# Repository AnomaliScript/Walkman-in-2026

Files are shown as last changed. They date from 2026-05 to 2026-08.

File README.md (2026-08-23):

# Walkman-in-2026
As a part of Hack Club's "Fallout" challenge, I attempt to build a replica of Makoto's walkman (from Persona 3) using KiCad, Onshape, and hopes and dreams.

This Walkman composes of many capacitors, resistors, an Audio Jack, a microSD card socket, LCD display, four buttons, an on/off switch, and most importantly, a XIAO-ESP3-S3 to make it all work!
Most, if not all of these components are THT, or "through-hole technology", meaning that the components have pins that go through holes in the PCB, making them easier to soldier, and that's why I chose THT components (with the exceptino of the microSD card reader), because I'm not a soldering expert (yet).

## V0.1
I made my own custom "standoffs" which are supports that support the LCD display, because it needs extra vertical room in order for its pins to be connected to the PCB.  I 3D printed both a "screw" and a "non-screw" version of the standoffs, to test which one would work best (standoffs are small, and the smaller a print is, the worse small details, like screw patterns, will be).



The screw standoff's didn't work, becasue my 3D printer can't print with that amount of sub-millimeter precision, so I'll just have to use the "non-screw" version of the standoffs.

## V0.2
The biggest change from V0.1 was the addition of an Amazon-purchased breakout board that covered both the AudioJack (3.5mm diameter) and PCM5102A stereo.  After all, the PCM5102A is indeed a really tiny chip, and with the soldering iron that I was getting, it wasn't likely that I could've soldered the chip using SMD (surface mount) on my own.  Consequently, I had to rewire the whole PCB (this will happen many times...) to compensate for this change.
What I specifically did was delete the AudioJack and PCM components from the PCB, and put a 16-pin connetor row in its place to set it up for wires to connect to the breakout module (a decision I would later go back on).
I also cleaned up the BOM a little bit, but it still was missing a lot of components compared to the final one (which I will link in the bottom of this README).



I was planning to get many of my components from my school's makerspace, however since Georgia school years end in mid-May, I lost access to those spaces, and therefore couldn't access those resources: this meant that I had to go shop online (i.e. Amazon and Digikey).
V0.2 was also when I finally started to consider how to power this whole contraption, and the conclusion I came up with was simply to add some punches holes (called  "Jumper" in the KiCad schematic) to have the battery wires solder through.





## V0.3
The buttons on the Walkman PCB looks a bit off; maybe it's because they're not tilted 90 degrees!  While implementing right-angle switches, I learned about the different types of drill holes that KiCad offers (I had the wrong type of hole for the switches' footprints which was giving me DRC errors).



This was also when I became very insecure about my power management system, so this was when I learned that the XIAO-ESP3-S3 in fact has a built-in nattery management system that rules out the need for Buck converters and other auxillary power managemtn components, which was a huge relief after having done power research for a couple of days straight.  The only problem was how to get the power tracks/wires to connect to the bottom of the XIAO, becasue that's where the XIAO's battery pads (BATT) are.  Seeing as to how laying the XIAO against teh PCB would make it impossible for a wire to reach under the XIAO, I decided to elevate it using connectors (not shown in the KiCad 3D Viewer below).



## V0.4
I went back on my decision to physically elevate my XIAO from the PCB.
After a family vacation, my refreshed mind preferred to create pads on the XIAO footprint itself.  By adding the BATT pads onto the footprint itself, the XIAO, when it comes in contact with the PCB direcly, would have its BATT pads touch the PCB's corresponding pads, requiring no extraneous equiment to connect the two.
This customization of the orignal XIAO-ESP32-S3 footprint required me to refer to Seeed Studio's offical KiCad files in order to determine the dimensions and position of the BATT pads, becasue the XIAOs that I ordered were still in transit at the time, so I had no other reference.



The XIAO BATT pads and its PCB footprint counterpart, in theory, seemed to perfectly align with each other.



I also learned that I had ordered the wrong type of switch for the power, as I ordered a SW_SPST (a button) instead of a SW_DPST (an actual power switch that toggles), so I had to order SW_DPST switches.
The LCD that I got was also an unexpected (but plesant) surprise: it came with the PCF8574 component (a component that allows for more GPIO pins) already soldered onto the LCD1602.  After realizing that this aligned with my PCB schematic, I gladly deleted the PCF8574 from my schematic and PCB Editor, and more configuration was done.



Due to the unique pin that the LCD came with, however, I had to redo the footprint for the LCD as well.





## V0.5
Reviewing my the PCB, I realized that the 5V pin on the LCD wasn't connected to anything, and thus began the **third** reexamination of my PCB's power management.  After scrutiny, I fixed the 5V pin on the LCD fairly quickly (connect the 5V on the LCD to the VBUS pin on the XIAO), but there was another issue that I found, and it had to do with the BSS138 components.  BSS138s are what are called "bidirectional I2C level shifters", which means they mediate the translation between a higher voltage (e.g. 5V) and a lower voltage (3V).  Cleaning up my schematic to mitigate risks of making errors due to confusion, I then revised the BSS connections.



Once again, I had to rewire everything (BSS138 is a surface-mount/SMD component, which made rerouting a little harder).



I also noticed that I really needed a 3D model for the LCD component, becasue that was not only the biggest part, but it's also one of the most important parts when it came to me designing a housing/case for my PCB.  Surfing through the internet, I landed upon a sketchy-looking 3D model of the exact same component (I copied and pasted the Amazon name of the component into Google), and it was in some Autodesk-specific file format.  After registering for a free trial for Autodesk products (specifically Fusion 360), I converted into an .stl file and imported into OnShape to look at it further.  The model  wasn't that bad, and when I linked the 3D model to my LCD footprint on the PCB in KiCad, it fit right in!
One tiny change had to be made, and it was the deletion of the right-angle pins (I bent the pins on my LCD to make it straight to make it parallel to the PCB surface...I hope that doesn't mess up dimensioning...)

## V1.0
Remember the 16-pin connector that I mentioned?  Their job was to act as pins that wires from the AudioJack breakout module could connect to, but seeing as to how it adds unnecessary space to the Walkman, I designed the AudioJack component as a footprint in the PCB Editor to get rid of the 16-pin connector (this did in fact save a lot of space).  This required some dimensioning, which I did, and I made a rough OnShape model of it.  Exporting it onto the 3D Viewer in my PCB Editor on KiCad, I moved it up a bit (which will represent me using pinn connectors to elevate it) in order to give it some room so it doesn't collide with the right-angle switches.





I utilized my 3D printer to print simplified versions of my PCB to check the footprints and pin dimensions for the XIAO, LCD component, and AudioJack component (not pictured), but after verification I ordered the PCB from JLCPCB, and now I wait for it to come (as well as some other LCSC components).





# BOM (not including delivery fees + tariffs)
| Id | Name | Vendor  | Qty | Cost |
| --- | --- | --- | --- | --- |
| 1 | [microSD card slot](https://www.digikey.com/en/products/detail/molex/0472192001/3044807) | DigiKey | 10 | $14 |
| 2 | [BSS138](https://www.digikey.com/en/products/detail/onsemi/BSS138/244210)| DigiKey | 10 | $2 |
| 3 | [Power Switch (taken from my friend's recommendation)](https://www.lcsc.com/product-detail/Slide-Switches_C-K-OS102011MA1QN1_C226259.html) | LCSC | 10 | $5.25 |
| 4 | [XIAO ESP32S3](https://www.amazon.com/ESP32S3-2-4GHz-Dual-core-Supported-Efficiency-Interface/dp/B0DJ6NQFKX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) | Amazon | 3 | $27 |
| 5 | [1602 LCD + PCF 8524 module](https://www.amazon.com/Hosyond-Display-Module-Arduino-Raspberry/dp/B0BWTFN9WF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) | Amazon | 3 | $14 |
| 6 | [AudioJack + PCM 5102 module](https://www.amazon.com/PCM5102-PCM5102A-Digital-Converter-Raspberry/dp/B0DNW32Y46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) | Amazon | 2 | $9 |
| 7 | [1000mAh LiPo battery](https://www.amazon.com/1000mAh-battery-Rechargeable-Lithium-Connector/dp/B07BTWK13N) | Amazon | 1 | $9 |
| 8 | [Right-Angle Switches](https://www.lcsc.com/product-detail/C49101620.html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) | LCSC | 50 | $0.63 |
| X | X | X | X | ~$81 |

## Additional supplies

I started to get soldering supplies by asking my friend's dad for some, to which he responded with a simple roll of solder and an okay soldering iron.  This worked out fine for the simpler components, but when it came to more complex soldering assemblies such as SMD components, I needed help.
After some discussion with by more-experienced friend, he told me that I needed a pack of liquid/solid flux (just in case if the rosin-core solder didn't have enough), a heatbed for the SMD components, and some solder paste to complement the heatbed for easier soldering for SMD components.
| Id | Name | Vendor  | Qty | Cost |
| --- | --- | --- | --- | --- |
| 1 | [Heatbed](https://www.amazon.com/Soldering-Microcomputer-Technicians-Electronics-Enthusiasts/dp/B0G443BG4X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) | Amazon | 1 | $27 |
| 2 | [Flux](https://www.amazon.com/SRA-Soldering-Electronics-Lead-Free-Electrical/dp/B008ZIV85A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) | Amazon | 1 | $9 |
| 3 | [Solder Paste](https://www.amazon.com/Particle-Melting-Electronics-Welding-100G/dp/B0FYH9HS2W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) | Amazon | 1 | $22 |

After getting these components, I set up shop in my garage, and I opened the garage door so that the yummy lead fumes could escape.  However, I got moved to my back patio after my dad complained after a bunch of bugs came it in from the open garage door.

Finally, after having done most of the soldering to enable theoretical functionality for my Walkman, I tried hooking it up to my computer using a Logi USB-C cable, and after some vibecoding with Claude Opus, I got the Walkman to work...partially.  The display was a little off, and no matter how many times I unplugged and replugged my earbuds, I still couldn't hear anything from the Walkman.  Thankfully, the microSD card reader was working, as well as the LCD after some adjustment, because I saw it displaying the text of the songs that I had loaded onto the microSD card.

Switching out my earbuds for headphones that I usually use, I was finally able to hear the music that was playing!



However, the battery still needed to be implemented into the Walkman PCB, and I soon realized that the V1.0 Walkman PCB wouldn't be able to distribute the LiPo battery's power to all the peripherals on the PCB.  This was because I wired the AudioJack, LCD display, and all the other peripherals other than the microSD card to all use VBUS (5V) power instead of 3.3V power.  The problem lied in how the 3.3V pin, not the VBUS pin, was the only power distributor when the Walkman is disconnected from the XIAO's USB-C's power source.

## V2.0 
With the LiPo power distribution not working and the LCD screen not being entirely accurate to Makoto's Walkman in Persona 3, I returned to the drawing board that is KiCad.  By working with Claude, I found another [LCD screen](https://newhavendisplay.com/2x20-character-lcd-stn-gray-display-with-side-white-backlight-and-pin-header-3v/) online that looked more similar to Makoto's Walkman screen.  Looking at its datasheet, I tried adding it into my Walkman PCB schematic.

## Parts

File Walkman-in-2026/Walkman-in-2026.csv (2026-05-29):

Id | Designator | Footprint | Quantity | Designation | Supplier and ref
1 | C1, C2 | C_Disc_D3.0mm_W1.6mm_P2.50mm | 2 | 2.2
2 | C3, C5 | C_Radial_D5.0mm_H5.0mm_P2.00mm | 2 | 2.2
3 | C6, C7, C8 | C_Disc_D3.0mm_W1.6mm_P2.50mm | 3 | 0.1
4 | C9 | C_Radial_D5.0mm_H5.0mm_P2.00mm | 1 | 0.1
5 | C10 | C_Radial_D5.0mm_H5.0mm_P2.00mm | 1 | 10
6 | J1 | Jack_3.5mm_CUI_SJ1-3513N_Horizontal | 1 | AudioJack3
7 | J2 | microSD_HC_Molex_47219-2001 | 1 | Micro_SD_Card
8 | J3 | Molex_KK-254_AE-6410-02A_1x02_P2.54mm_Vertical | 1 | Conn_01x02_Socket
9 | Q1, Q2 | SOT-23 | 2 | BSS138
10 | R1 | R_Axial_DIN0207_L6.3mm_D2.5mm_P7.62mm_Horizontal | 1 | 33
11 | R2, R3, R4, R5, R6 | R_Axial_DIN0207_L6.3mm_D2.5mm_P7.62mm_Horizontal | 5 | 1k
12 | R7, R8, R9, R10, R11 | R_Axial_DIN0207_L6.3mm_D2.5mm_P7.62mm_Horizontal | 5 | 10k
13 | R12, R13 | R_Axial_DIN0207_L6.3mm_D2.5mm_P7.62mm_Horizontal | 2 | 470
14 | SW1, SW2, SW3, SW5, SW6 | SW_PUSH_6mm | 5 | SW_Push
15 | SW4 | SW_SPST_Omron_B3F-315x_Angled | 1 | SW_SPST
16 | U1 | XIAO-ESP32-S3-DIP | 1 | XIAO-ESP32-S3-DIP
17 | U2 | LCD1602 | 1 | HS1602A-B
18 | U3 | TSSOP-20_4.4x6.5mm_P0.65mm | 1 | PCM5102
19 | U4 | DIP-16_W7.62mm | 1 | PCF8574P

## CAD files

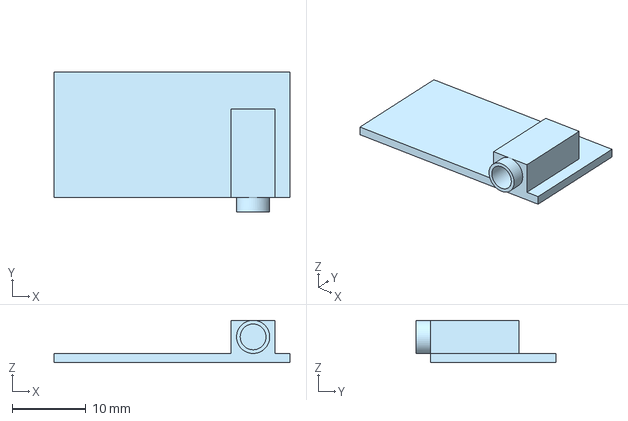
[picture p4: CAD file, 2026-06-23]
Walkman-in-2026/3d models/PCM + AudioJack.step
32.0 x 19.0 x 5.75 mm

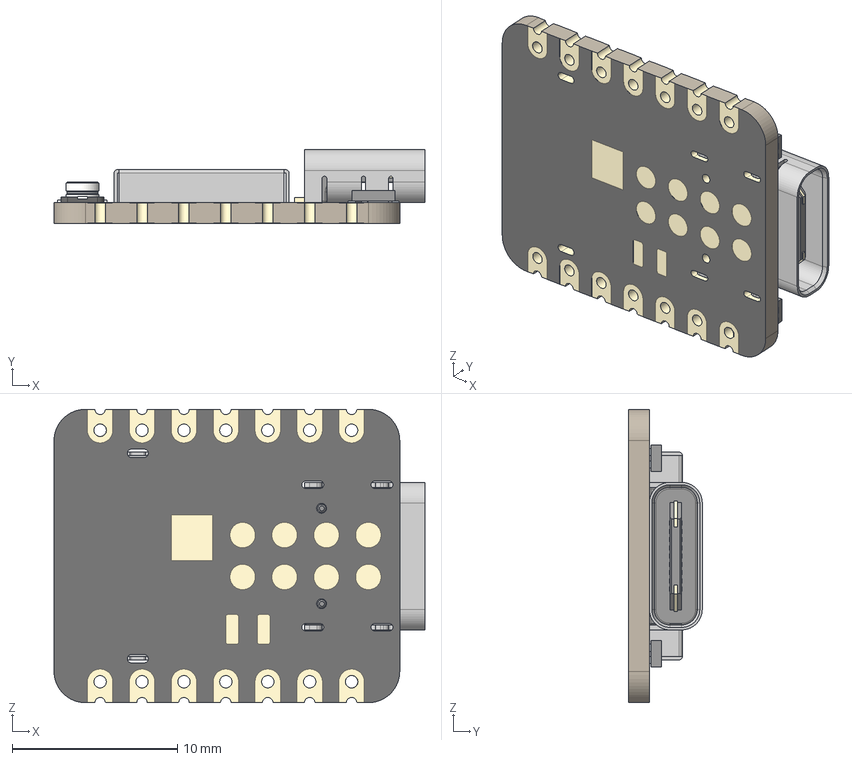
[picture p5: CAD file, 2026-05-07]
Walkman-in-2026/3d models/seeed-studio-xiao-esp32s3-3d_model/XIAO-ESP32S3 v2.step
22.5 x 4.46 x 17.8 mm
BOSS-EXTRUDE14_8_
BOSS-EXTRUDE7_4_
BOSS-EXTRUDE7_3_
BOSS-EXTRUDE14_4_
BOSS-EXTRUDE14_2_
BOSS-EXTRUDE14_11_
BOSS-EXTRUDE7_7_
BOSS-EXTRUDE14_9_
BOSS-EXTRUDE14_3_
BOSS-EXTRUDE14_7_
MIRROR2
BOSS-EXTRUDE14_5_
BOSS-EXTRUDE14_12_
BOSS-EXTRUDE7_8_
BOSS-EXTRUDE7_1_
BOSS-EXTRUDE14_10_
BOSS-EXTRUDE7_9_
BOSS-EXTRUDE14_6_
BOSS-EXTRUDE14_1_
BOSS-EXTRUDE7_6_
BOSS-EXTRUDE7_2_
CUT-EXTRUDE5
BOSS-EXTRUDE7_5_
Shield
Pins x 2
U.FL-R-SMT-1_10_ v1

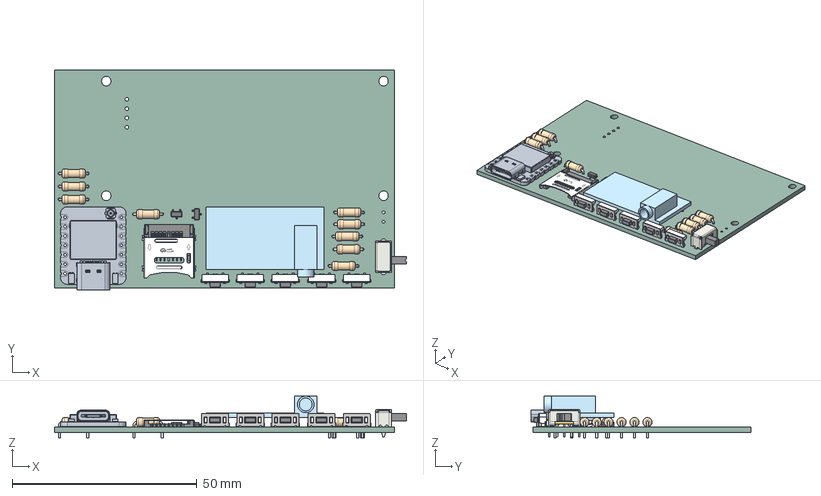
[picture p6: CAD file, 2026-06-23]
Walkman-in-2026/walkman v1.4.step
95.2 x 59.5 x 11.3 mm
XIAO-ESP32S3 v2
SW-SMD_TC-S3601-3.5-260G-F0.6 x 5
PCM + AudioJack
R_Axial_DIN0207_L6.3mm_D2.5mm_P7.62mm_Horizontal x 9
TF-SMD_472192001
SW_Slide_SPDT_Angled_CK_OS102011MA1Q
Surface 2
Surface 66
Surface 50
Surface 34
Surface 18
Surface 98
Surface 82
Surface 64
Surface 48
Surface 32
Surface 16
Surface 96
Surface 80
Surface 62
Surface 46
Surface 30
Surface 14
Surface 94
Surface 78
Surface 20
Surface 27
Surface 4
Surface 11
Surface 84
Surface 91
Surface 68
Surface 75
Surface 52
Surface 59
Surface 36
Surface 43
Surface 25
Surface 9
Surface 100
Surface 89
Surface 73
Surface 57
Surface 41
Surface 23
Surface 7
Surface 87
Surface 71
Surface 55
Surface 39
Surface 3
Surface 67
Surface 51
Surface 35
Surface 19
Surface 1
Surface 99
Surface 83
Surface 65
Surface 49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

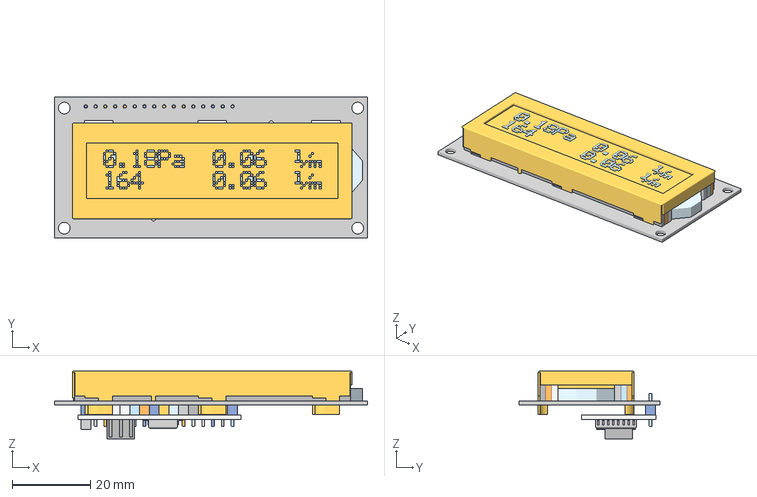
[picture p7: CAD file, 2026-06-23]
Walkman-in-2026/3d models/LCD 1602 I2C (pin removed).step
80.0 x 36.0 x 17.3 mm

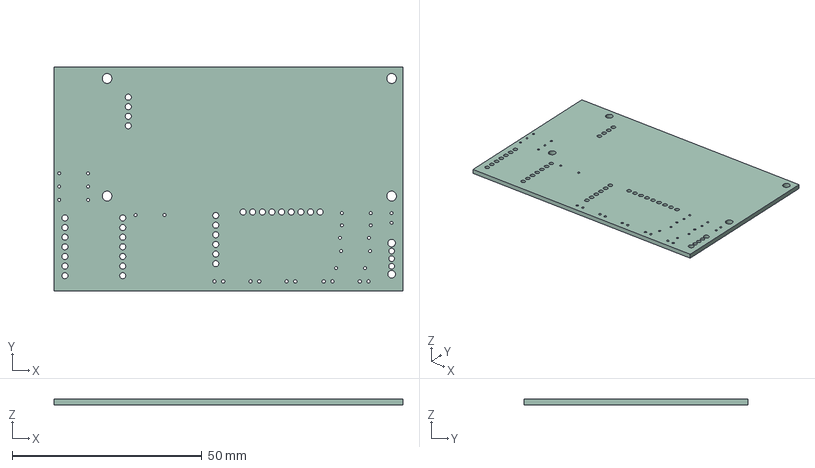
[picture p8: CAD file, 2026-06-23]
Walkman-in-2026/walkman v1.4 board.step
92.0 x 59.0 x 1.51 mm

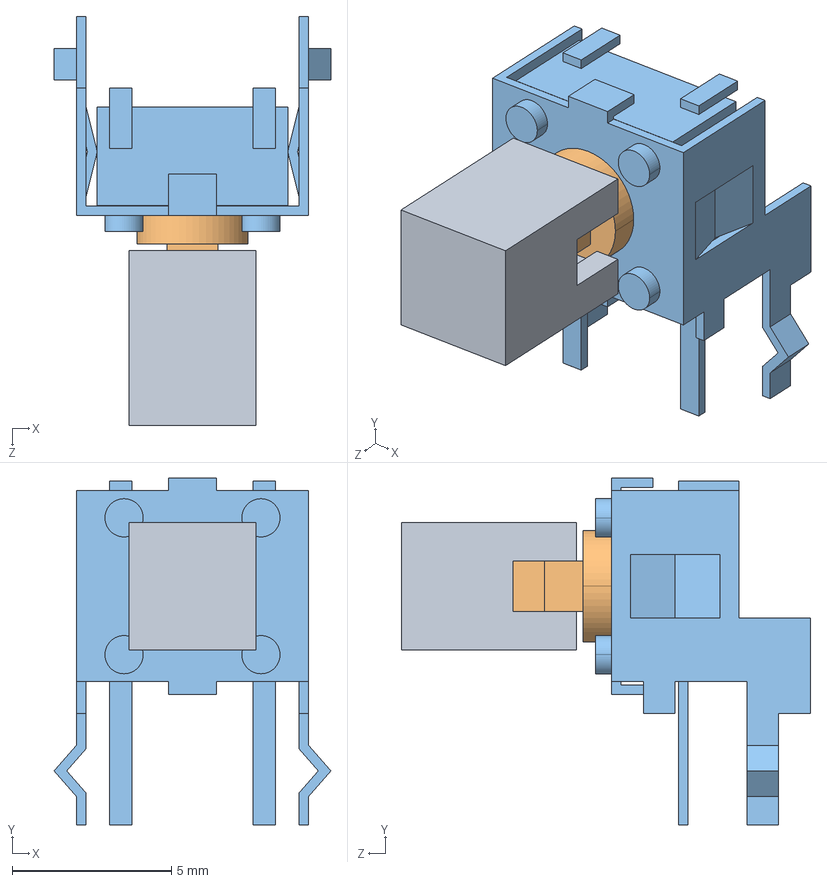
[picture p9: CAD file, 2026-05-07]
Walkman-in-2026/3d models/B3F_3150.step
8.70 x 10.9 x 12.9 mm
B32_1000
B3F_3150_BUTTON
B3F_3150_BASE

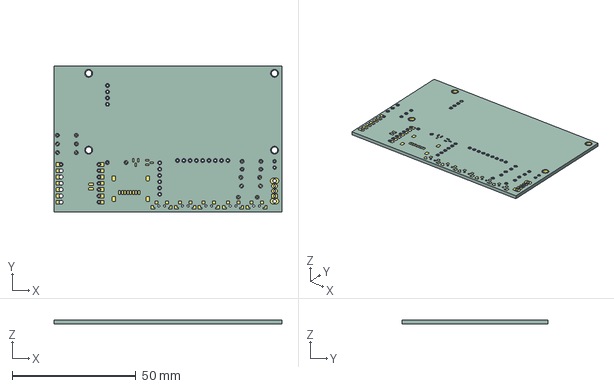
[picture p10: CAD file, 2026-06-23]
Walkman-in-2026/walkman v1.5 board (pads).step
92.0 x 59.0 x 1.59 mm
Walkman-in-2026_pad
Walkman-in-2026_PCB

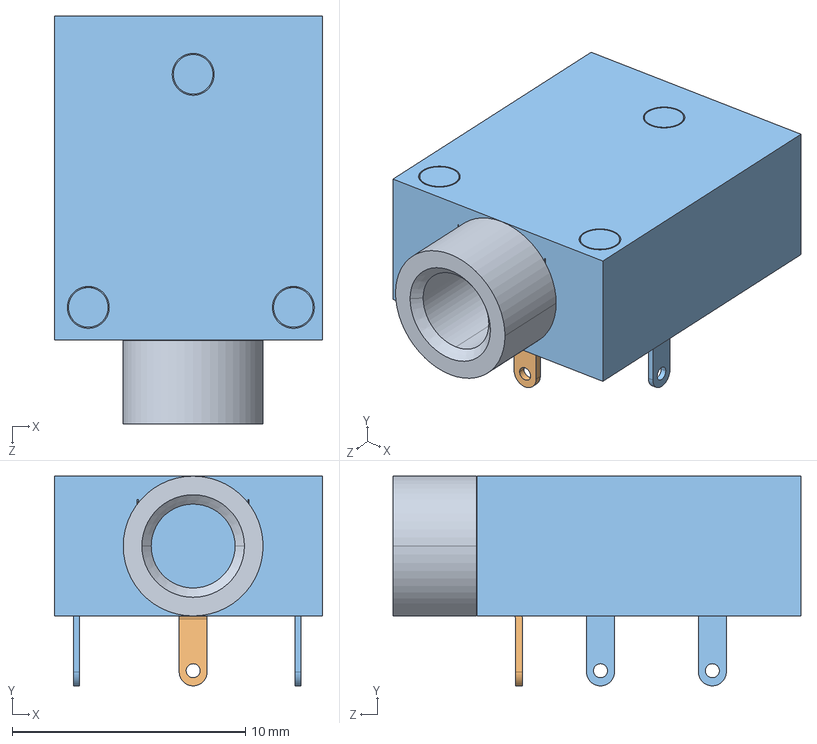
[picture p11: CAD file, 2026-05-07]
Walkman-in-2026/3d models/Same_Sky_SJ1-3513N.step
11.5 x 9.00 x 17.5 mm

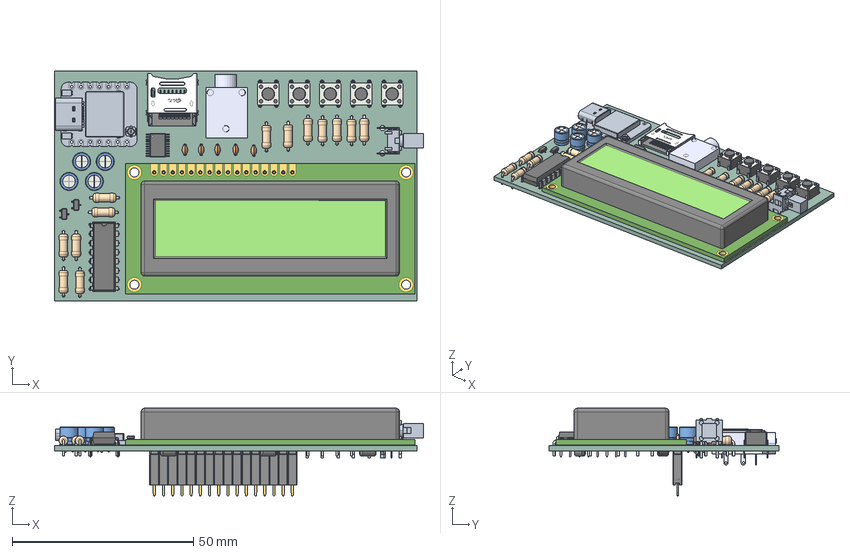
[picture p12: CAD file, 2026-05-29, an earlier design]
Walkman-in-2026/old_models/walkman v0.step
101.9 x 63.5 x 24.2 mm
C_Radial_D5.0mm_H5.0mm_P2.00mm x 4
C_Disc_D3.0mm_W1.6mm_P2.50mm x 5
XIAO-ESP32S3 v2
SW_PUSH_6mm x 5
R_Axial_DIN0207_L6.3mm_D2.5mm_P7.62mm_Horizontal x 13
TF-SMD_472192001
B32_1000
B3F_3150_BUTTON
B3F_3150_BASE
LCD1602̜ͥ
HDR-M-2.54_1x16-Áã¼þ
HDR-F-2.54_1x16-Áã¼þ
SOT-23 x 2
TSSOP-20_4.4x6.5mm_P0.65mm
DIP-16_W7.62mm
Same_Sky_SJ1-3513N
Walkman-in-2026_PCB

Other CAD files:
Walkman-in-2026/walkman v1.5 board.stl
Walkman-in-2026/walkman v1.5 board (pads).stl

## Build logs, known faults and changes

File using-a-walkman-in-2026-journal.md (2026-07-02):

# Using a Walkman in 2026 — Journal Export

- Exported at: 2026-07-02T14:07:46Z
- Project ID: 2332
- Entries: 37

## Entry 1
- ID: 3008
- Author: Brandon
- Created At: 2026-04-20T03:36:53Z

### Content

Today, I started my KiCad journey into making my Walkman actually happen, where I read up on the tutorial for KiCad, and did some research: it turns out the preferred MCU for my Walkman would be the **XIAO-ESP32-S3** (according to Gemini) because of its Bluetooth capability, because I would like the option to switch to my AirPods if wired earbuds got too annoying.

I looked further into the differences between the C6 and the S3 variants.




WHAT? You're telling me there's more than one type of ESP23-S3?!


I later learned that these differences are based on how the components will be attached to the solder board, and used this YouTube video to educate myself on how each type of manufacturing style works: https://youtu.be/UwTBCpqqacU?si=3JkgFAU-7ZSq832C (huh, this video also has Chinese captions)
I ended up choosing the SMD_PAD manufactured one, as it will allow me to hand-solder the part onto the PCB.

After this, I pursued to find a display for my Walkman replica: one that was thin and slim, but not too slim.  I finally found one on LCDC: https://www.lcsc.com/product-detail/C18198249.html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
Importing it into KiCad (specifically the Schematic) eas a nightmare.  Even through there was a gudie that helped me what to do, it still took me an hour and then some to get just the display of it on there: from using Gemini to watching Indian YouTube tutorials, I did it all, and found the schematic with two things: the ESP32 and the OLED Display screen.

### Recording Links

- https://lookout.hackclub.com/api/media/1aadc8eb-a1a8-465c-8510-a7b3c4f2bbd3/video.mp4

## Entry 2
- ID: 3151
- Author: Brandon
- Created At: 2026-04-21T03:36:40Z

### Content

Today was a full-on research day, where I learned about DACs (Digital Analog Connectors iirc?) and how they are important to translate audio data into a form where I can listen to music through a head phone jack (J1).
And because this is a music-playing device, I had to have a storage of some kind...hm....a microSD card!
Unfortunately, the poor XIAO didn't have enough room/pins to handle both the LCD display and the pins required for the MicroSD card (I also learned about MISO and MOSI pins for storage components like microSD cards).  Thus, I had to use a thingy called I2C (Inter-Integrated Circuit, I think), which is a technology that connects components together, especially peripherals.  This also meant: MORE PINS! YAY!

Unfortunately, it's bedtime, so I'll work on using Claude to help me know where each pins go.  I also looked up some of my first datasheets today: I'm starting to feel like a electrical engineer now!
(This is the datasheet for the pcm5102, which I'm pretty sure is a DAC that does the analog audio data translating for my headphone jack).
Screenshot 2026-04-20 232044.png

### Recording Links

- https://lookout.hackclub.com/api/media/c7bf1d50-8d7d-4dc5-8d09-0e8311dab583/video.mp4

## Entry 3
- ID: 3813
- Author: Brandon
- Created At: 2026-04-25T03:59:19Z

### Content

I am so close to breaking my streak it's 11:51PM rn T-T
Today was a wild PCB designing day for me...let be begin by talking about my trying to free up a pin for my Resistor Ladder on the XIAO ESP32 S3.  Basically it needed an analog pin (ADC) but all the rest of the pins on the MCU were taken by the LCD display pins, so I had to import and look for a I2C backpack (PCF8574P) to implement in my PCB.  After spending a while adding the PCF8574P to my schematic, I connected the display pins to the PCF8574P, and rerouted the Resistor Ladder with all my switches (buttons) go to the XIAO's now-free A0 pin.  Yippee!

After, I worked on the 3.3V (XIAO and PCF8574P) and 5V (LCD) difference, because wiring those together would "wear out" the PCB, so I've heard, so I chose to add a MOSFET (BSS138) to the PCB to manage that.

There's a lot more I can talk about, but I need to turn in my journal in now, I'll talk about it more in my next entry, bye for now!
Screenshot 2026-04-24 234217.png

### Recording Links

- https://lookout.hackclub.com/api/media/1ea78349-316f-401f-9d6a-252b5c26c8a0/video.mp4

## Entry 4
- ID: 3963
- Author: Brandon
- Created At: 2026-04-26T00:39:55Z

### Content

Review of what I did in the last journal entry, since couldn't complete the full entry due to me having to submit it before midnight (I submitted it at 11:59PM!)

_I learned all about the different pins that the Micro SD Card had, and how their pins relate to the MOSI and MISO pins in the XIAO ESP23-S3.  The data goes into the MOSI from the card, and the MISO sends out data to the card...I think.  Anyways, I used Claude to help me summarize a datasheet for the stereo ADC that I had to use to bridge between the AudioJack and the XIAO ESP23, and it turns out that TI (Texas Instruments), really wants me to put a whole slew of caps (capacitors) onto their PCM5102 to ensure "safety" or something...not quite sure of the exact reason yet...and after getting the news that I had to place a bajillion caps on there, I signed off for the night.  

And that is where we continue my Walkman journey today..._

Continuing where I left off yesterday night, I had a hard time connecting the rest of the pins and learning about the audio stereo ADC component that I was working with (specifically, the PCM5102).  **This was because I had to work on my PCB with my battery-deficient laptop, where it almost constantly had to be connected to a power outlet, and I even forgot to bring my mouse!**


What will I do without my precious right-click and scroll-wheel? T-T  (For context about why I didn't have access to my desktop is because I was volunteering at a jazz music festival all-day today)

Thus, I accomplished less than what I hoped for.
During this session, I also learned about "bypass capacitors", which are mechanisms where a capacitor is placed between a GND (ground) point and intersection where power is flowing to the pin (in this case, the CPVDD, DVDD, and AVDD pins ) in order to manage power "spikes" that would happen that result from turning switches on and off.


Luckily, I finally ended up with my first version of the (what is think is the) entirety of the schematic, now I just have to check it!  (Ugh, checking...)

### Recording Links

- https://lookout.hackclub.com/api/media/7c59ccf2-c480-4df7-b77c-4ef2a79f002e/video.mp4

## Entry 5
- ID: 3987
- Author: Brandon
- Created At: 2026-04-26T03:27:34Z

### Content

This time, I was pressed for time and I only could ask Claude for the BOM about what specific materials and component models I should get for the resistors, AudioJack, capacitors, etc for all the stuff that I was going to need to solder onto the board.

Claude gave me the difference between THT and SMD socket components, which led me to make some decisions (as I had some experience with soldering before through my robotics club, I thought that I would be able to hit them up for some soldering help for SMD soldering to help preserve space on my PCB).
Screenshot 2026-04-25 224140.png

### Recording Links

- https://lookout.hackclub.com/api/media/c29a6eed-b1fe-4980-970e-7d8049d6ec55/video.mp4

## Entry 6
- ID: 3991
- Author: Brandon
- Created At: 2026-04-26T03:46:02Z

### Content

This session was really short, because I was doing this between chores (my parents are inviting friends over all of a sudden T-T)
Anyways, I continued my research into seeing if the Molex version of the aforementioned microSD Card reader is the same as the microSD Card reader that I chose in the KiCad footprint editor: I'll have to look at KiCad's rendition of the dimensions of the microSD Card Reader in my next session.
However, I did manage to get some dimensions of the microSD Cards that are available on LCSC, a sister company of JCLPCB that share many of the same supplies and components, so I hope there's a high chance of seeing the exact component that was listed in KiCad.



### Recording Links

- https://lookout.hackclub.com/api/media/58d2fc34-4e16-444e-9bb2-855d7b3ae880/video.mp4

## Entry 7
- ID: 4285
- Author: Brandon
- Created At: 2026-04-28T01:03:31Z

### Content

In this session, I went into the footprint editor for some of the components (in the following screenshot I inspect the microSD Card reader by molex), and sure enough, these dimensions match the ones listed in their datasheets!
Screenshot 2026-04-27 182044.png

After that, I went through all of these components and used the Internet and Claude to search for which components would be best for my project:
- Audio Jack
- Switches (Buttons)
- Switches (Single Pole Single Throw switches)
- Resistors
- Capacitors

For example, here is the list of all the buttons that I was considering:
Screenshot 2026-04-27 182501.png

During the process of looking for resistors, I got to refresh some of my Physics class learnings by using Ohm's law to try to calculate the required Power (in Watts) that a resistor had to have in order to be suitable for different parts of my PCB.  I learned the Power Law (i.e. P = I^2 * R) by doing this, and Claude helped me go through the formulas and calculations. (Of course, I could've gotten it to just tell me what products to get, but I like to know the "why" behind technical things like this!)

I also learned about the different kinds of resistors available to me (I chose the SW_PUSH_6.0mm one):
[](url)
Screenshot 2026-04-27 184148.png

As I finished the BOM, I realized that I may not need an audio jack, because **my wired earbuds that I have in fact use the Lightning cable**...so I'll have to fix that before I move onto the PCB editor.

### Recording Links

- https://lookout.hackclub.com/api/media/3459b02a-e108-41c2-8270-5c5de9bcffd9/video.mp4

## Entry 8
- ID: 4342
- Author: Brandon
- Created At: 2026-04-28T12:22:34Z

### Content

Today I cleaned up the PCM wiring, because I made the mistake of trusting Claude to do all the thinking of telling me where to wire things for me.  Even though I gave it the pdf of the PCM 510x datasheet, it still messed up some things for my schematic.  Some intersections between wires were missing, and the direction was off in all the wiring, although Claude had gotten all the resistances and powers right for the capacitors and resistors.
Here's the real configuration of the PCM according to Texas Instruments:


This was a headache figuring this out, as I had to move other components on the schematic to make room for rewiring the PCM.

After getting that sorted out, I was unpleasantly surprised to see that I was getting errors that KiCad couldn't find my MCU's footprint (i.e. XIAO_ESP32_S3) for the PCB Editor!  I had to scour through my /Documents, and sure enough, I forgot to include the .pretty folder that was supposed to contain the footprint for the MCU.  Going back to the page where I originally got the XIAO_ESP32_S3 for the schematic (https://wiki.seeedstudio.com/XIAO_ESP32C3_Getting_Started/#resources), I downloaded the zipped footprint file, and placed it inside the GitHub-tracked folder, so that I could continue working on it on other devices.


After doing so, I hoped that the footprint would appear when I went int the "Assign Footprints" page, and surely enough, it was there!  I pressed F8 triumphantly, and went on to bring the last, but certainly not least, component onto the PCB editor.
Screenshot 2026-04-27 230242.png

...
There's going to be a lot of work to do in the next few days.
Organizing this mess will take a while.

Before I signed off, however, I placed all the components into a box-like shape, where the enclosing perimeter barely was within regulation (100mm x 100mm).  I'll have to squeeze these things tighter if I want to make this project happen!
Screenshot 2026-04-27 230855.png

Also here's what the reference of the XIAO_ESP23_S3 looks like in the PCB Editor compared against the real footprint of the MCU.  Turns out they're not the same.  That's so tricky, how the refence of the MCU can appear even if the .pretty file for it wasn't imported yet!
Screenshot 2026-04-27 230333.png

### Recording Links

- https://lookout.hackclub.com/api/media/d9cb07e5-026a-4644-827f-7c0e6f55e56c/video.mp4

## Entry 9
- ID: 4717
- Author: Brandon
- Created At: 2026-05-01T04:41:58Z

### Content

Today was all about the PCB Editor.  I tried to move around some wiring stuff, but there's only so much I could do with only a front and back copper wiring, and I soon had thousands of vias all over the PCB, which at that point I decided to reset EVERYTHING using KiCad's "Global Deletions" tool, and selecting all the copper paths, wires, and vias.


It was sad having to restart after I tried to make some headway into my wiring for the past 45 minutes, but it had to be done, in order to prevent more "via hell".  After I restarted, I moved the resistors to be above (farther up than) the LCD display, which simplified some wiring things.  I have to sleep now, but hopefully I can finish this wiring tomorrow and ask for someone to review it.

### Recording Links

- https://lookout.hackclub.com/api/media/f4e20d62-6b0a-4424-9013-4a711fbb8479/video.mp4

## Entry 10
- ID: 5224
- Author: Brandon
- Created At: 2026-05-03T04:49:09Z

### Content

Today I had to deal with PCB designing on my crappy laptop again because I was busy with scouting matches at the FIRST Championship in Houston (I stopped by the Hack Club booth, it was cool!)
Between bus rides back and forth from the hotel, I attempted to continue wiring my PCB together in KiCad's PCB Editor.
Screenshot 2026-05-01 080658.png
After a bit, I was trying my best to minimize the vias and make the routes as short as I could, but at a certain point, I decided to reset all the tracks and wiring and start over...again.
When taking a break from scouting matches at the FRC Championship, I came up with the brilliant (but obvious) idea of using the schematic to determine which components should be closer to certain components.
For example, I placed the XIAO ESP23 to be in the corner of the PCB, where it's more accessible to the PCM and PCF so not as much wiring would be required.
Screenshot 2026-05-02 200527.png

### Recording Links

- https://lookout.hackclub.com/api/media/081d1a5d-8d79-4d58-8523-e08076eebd12/video.mp4
- https://lookout.hackclub.com/api/media/9c58167b-8520-4ebc-a850-b66e88b1f017/video.mp4

## Entry 11
- ID: 5372
- Author: Brandon
- Created At: 2026-05-04T03:03:11Z

### Content

Today, I kept working at the track hell that I had to do...this time, the focus of my sessions was in the PCM side of things.  The PCM connects to resistors, MIcro SD, the XIAO, Capacitors, literally everything so this made my head dizzy.  Not to mention, all the pins leave to space between them to let tracks go in between them, and **they are all front-copper (red) pins!**
This is a picture of me resorting to rotate the PCM in order to try to find a better way to organize it so that it results in fewer cross-overs and via craziness (i.e. the PCM pins are closer to their destinations to a greater extent).  What you see here is what the tracks were left behind when I dragged the PCM out of the frame of the PCB in order to rotate it separate from the whole PCB chaos.
Screenshot 2026-05-03 222950.png
Finally, after grueling work (not really, but it was tedious) I got a version of the PCM wiring (with less than 15 vias! yay...).
I never verified that having less vias is better for a PCB, but according to my common sense, less vias -> better
Screenshot 2026-05-03 225528.png

### Recording Links

- https://lookout.hackclub.com/api/media/d54699b7-06cb-4a69-8d3b-d5952ae25e61/video.mp4
- https://lookout.hackclub.com/api/media/aa61b15c-58b1-4517-ae1a-48ab2f16fae1/video.mp4

## Entry 12
- ID: 5540
- Author: Brandon
- Created At: 2026-05-05T03:11:13Z

### Content

Today, I finally attempted to close out the tracks in the PCB design, and since I did the hard stuff before (i.e. the PCM and micro SD card pins), it was relatively easy for me to do.

What wasn't as easy, however, was running the DRC and troubleshooting every error and warning.  One of the first errors that I fixed was the overlap of these pink outlines of the components: they're called courtyards.

In my case, the two BSS components that I had had overlapping courtyards, and here's the before and after the error:
Screenshot 2026-05-04 220401.png
Screenshot 2026-05-04 220605.png

Moving it was a bit annoying, as I had to rewire and track every one of the tracks that were connected to it.  I looked up a way to be about to move the component only in KiCad and have the tacks connected to it update themselves, but what KiCad offered, the "Drag" tool (activated by pressing "d") didn't work very well in my PCB because of the sheer amount of track and wire action going on.

After, I noticed that I kept getting an error about "malformed Edge.Cuts" shape, and I was initially confused, until I realized that I never defined a shape for the PCB, and only defined silkscreen shapes to outline the rough size restrictions for my PCB (100mm x 100mm).  Following this, I unfortunately discovered that the XIAO-ESP23-S3's footprint was barely outside the Edge.Cuts border.  To fix this, I had to move the XIAO back into the PCB.
Screenshot 2026-05-04 222547.png

I wanted to see the current version of the PCB in its 3D form: here it is as of right now!
Screenshot 2026-05-04 225843.png

### Recording Links

- https://lookout.hackclub.com/api/media/d5e59945-c8f8-4c8d-9821-e8e7d1448bd1/video.mp4

## Entry 13
- ID: 5680
- Author: Brandon
- Created At: 2026-05-06T03:59:44Z

### Content

Today is the day where I import my Gerber files (zipped) into JCLPCB and see how much it costs!
Of course, I chose the cheapest delivery price, and it was pretty cheap (of it may be because all of the deals I'm getting as a new JCLPCB member).
Here's me realizing that I need to get to reimport the Gerber files because I forgot to include some of the files.
Screenshot 2026-05-05 231304.png
Screenshot 2026-05-05 231408.png
This is me ordering my last PCB project because I didn't finish the process of buying it last time.
Screenshot 2026-05-05 232029.png
Screenshot 2026-05-05 232422.png
I also exported the 3D rendering of my Walkman rn!
Screenshot 2026-05-05 234517.png

### Recording Links

- https://lookout.hackclub.com/api/media/bdf27283-ae1d-45e6-8739-f536f6d2cbec/video.mp4

## Entry 14
- ID: 5831
- Author: Brandon
- Created At: 2026-05-07T02:45:31Z

### Content

After getting some rest last night (I got to sleep in because of AP exams), I found all the rest of my 3D models for my PCB in order to get an accurate visual representation of my PCB so that I could import it into OnShape so that I can start making a 3D printed case for it to protect it.
During my importing process, I had to go file hunting in my Walkman/ and Program Files/KiCad/ folders, because when I use easyeda2kicad, it outputs the .step 3dmodel files for the components into the Program Files/KiCad/ and I placed them into my Walkman/ folder (that is being tracked using GitHub Desktop).  I did this to maintain continuity, dunno if this is bad file management as an electrical engineer.  (Guess I'll find out the hard way later)
Screenshot 2026-05-06 212219.png
Screenshot 2026-05-06 213040.png
Screenshot 2026-05-06 213817.png
Screenshot 2026-05-06 215306.png
For the SPST switch, KiCad didn't have the 3D model in its Program Files for some dumb reason, so I had to create an account for Omron [https://components.omron.com/us-en/](url) and downloaded the SPST switch 3D model directly from there (specifically, it was from the B3F series).
Screenshot 2026-05-06 221542.png
Here's what my PCB 3D rendering looks like now!  (Also sorry for the short journal entry yesterday: it was because I was writing up my entry at 11:58PM .-.)
Screenshot 2026-05-06 221612.png

### Recording Links

- https://lookout.hackclub.com/api/media/abaec749-8537-4eda-8e71-62728c9de4de/video.mp4

## Entry 15
- ID: 6201
- Author: Brandon
- Created At: 2026-05-09T03:59:42Z

### Content

So sorry but I have to use next journal entry to document my progress, the deadline (midnight) is coming up fast


### Recording Links

- https://lookout.hackclub.com/api/media/9289bfb3-3035-4c9d-a1b8-d4c7699f0ab0/video.mp4

## Entry 16
- ID: 6204
- Author: Brandon
- Created At: 2026-05-09T04:28:51Z

### Content

[This entry is for the last journal entry due to midnight closing in fast and I wanted to maintain my streak, thus the dummy Lookout Timelapse]
Diving deeper into 3D rendering inspection, I noticed that the pins on the LCD and the Audio Jack looked especially odd, and after fixing the Z axis of the Audio Jack in the 3D rendering, I went and asked Gemini what was going on with the LCD Display screen.
Screenshot 2026-05-08 213641.png
This wasn't my first time seeing the LCD's unique "blocky" pins compared to the other components, but I just never asked or questioned it up until this point.  Seeing that the pins just protrude through the PCB, I decided to finally find out what is actually supposed to happen with that LCD display.  Turns out, after research and looking at this [video](https://www.youtube.com/watch?v=qkb5_Wu0lgk), I couldn't believe that this LCD is supposed to be "dangling", only supported by the blocky pins that it has--well that's the way it is, I guess.
Screenshot 2026-05-08 214419.png
So after this discomforting discovery, like a good STEM student, I was concerned about the LCD display's support and the possibility of it breaking off or bending the pins (even though I going to build a case for it anyways).  This led me to the discovery of "standoffs", which are supports built for the corner holes in the LCD display.
Screenshot 2026-05-08 233544.png

Screenshot 2026-05-08 233922.png
After doing some more digging, I conveniently found a file for 3D printing these "standoffs", and given that I have a 3D printer, this worked out for me!  (I found the 3D prints [here](https://www.thingiverse.com/thing:4963899))
Screenshot 2026-05-08 234053.png

### Recording Links

- https://lookout.hackclub.com/api/media/e649ba19-e280-4b08-a3d2-dc83b9d8bf2d/video.mp4

## Entry 17
- ID: 6374
- Author: Brandon
- Created At: 2026-05-10T03:48:45Z

### Content

I made my own custom "standoffs" which are supports that support the LCD display, because it needs extra vertical room in order for its pins to be connected to the PCB. I 3D printed both a "screw" and a "non-screw" version of the standoffs, to test which one would work best (standoffs are small, and the smaller a print is, the worse small details, like screw patterns, will be).
Screenshot 2026-05-09 231951.png
Screenshot 2026-05-09 233715.png
I sliced my custom 3D prints using OrcaSlicer (despite not having my PCB and components on hand yet because I was waiting on another PCB to be shipped first), and decided that I needed to thicken some of my standoff and nut dimensions, because the slicer gave me a reality check about how small these things actually were.
Also, I made sure to send the sliced 3D prints to my 3D printer by running to my printer and turning it on, and then running back to my computer to send the files via OrcaSlicer (and no, I did not start printing during when the Lookout was recording my session)
Screenshot 2026-05-09 232901.png
So smol they only need one popcorn 🥹

### Recording Links

- https://lookout.hackclub.com/api/media/1fb45dbc-32ee-447d-84f2-66c8de7aed37/video.mp4

## Entry 18
- ID: 6872
- Author: Brandon
- Created At: 2026-05-13T03:56:45Z

### Content

I had to review the datasheet and information about the XIAO-ESP32-S3 again with [this link](https://wiki.openelab.io/seeed-studio/xiao-esp32s3).
This session challenged me a lot, and by "challenge" I mean it reminded me that PCBs need batteries in order to run portably.  (Well duh...)
Ok, in my defense, I assumed that the XIAO having battery power management to be able to take in power without needing a middleman meant that it could store power independent of other sources, but no, I was wronggggg.
Before that, though, I did some researching about the volumes that I could play my "jukebox" at, and I found a cool table that broke down what configurations would give me different sounds (I chose 12dB gain, I want my music to be heard!):
Screenshot 2026-05-11 211124.png
I was also given a pinout diagram, which was a cool find (and useful, these things are just copy-paste :D)
Screenshot 2026-05-11 212826.png
Back to the main topic: I FORGOT ABOUT THE BATTERIES (for BOTH the Walkman project and the Jukebox project, for the latter of which it wasn't such a big deal).  
For the Walkman project:
After scrambling to find some way to get a wire from my battery connected back to the PCB, which has to be externally connected (from the back of the PCB) due to space constraints and aura loss (I mean, who wants to have a big brick hanging on their lanyard like that?  Remember, I want the Walkman to be as similar to Makoto's thingy as possible).  Anyhow, I tried using a Screw Terminal to connect the battery pack (LiPo) to the GND
Screenshot 2026-05-11 223233.png
But when I placed it on the PCB editor, I saw that it was way too big for my PCB!  So I went to using a Connection, specifically a Socket (TIL why Pins are called Male, and why Sockets are called Female T-T), and it works, at least theoretically.
Screenshot 2026-05-11 230914.png
Screenshot 2026-05-11 231211.png

### Recording Links

- https://lookout.hackclub.com/api/media/4b8c3a1d-cc57-4bab-ba8d-4bc89226e726/video.mp4

## Entry 19
- ID: 7857
- Author: Brandon
- Created At: 2026-05-18T20:51:27Z

### Content

Today was all about shopping, and the websites I went to were mainly:
1. DigiKey
2. Molex (which had links that lead to DigiKey sites)
3. Mouser Electronics
4. Amazon <3
After some product research, I went ahead and organized all the components on my BOM in different categories, as shown below:

I tried to export a BOM from the PCB Editor, but that didn't end up being too helpful: I resorted to typing the component's footprint's name into Google directly (it worked).
I also had to review a ton of the components to make sure that they were compatible with my PCB.  How did I do that? not with dimensions, but with model numbers and just eyeballing it (I am not about to check every single dimension T-T)
Screenshot 2026-05-18 155917.png

Here are all the purchasing links of what I got so far:

[microSD card reader](https://www.digikey.com/en/products/detail/molex/0472192001/3044807)

[Conn 01x02](https://www.digikey.com/en/products/detail/molex/0022272021/1130577)

[AudioJack](https://www.digikey.com/en/products/detail/cui-inc/SJ1-3513N/CP1-3513N-ND/738686)

[BSS138](https://www.digikey.com/en/products/detail/onsemi/BSS138/244210)

[XIAO ESP32-S3](https://www.amazon.com/ESP32S3-2-4GHz-Dual-core-Supported-Efficiency-Interface/dp/B0DJ6NQFKX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)

[PCF8574P Output Extender](https://www.amazon.com/Bridgold-PCF8574P-PCF8574AP-Extender%EF%BC%8C2-5V-6V%EF%BC%8CDIP-16/dp/B0GF1Q1GNG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)

[LCD 1602 screen](https://www.amazon.com/Hosyond-Display-Module-Arduino-Raspberry/dp/B0BWTFN9WF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)

### Recording Links

- https://lookout.hackclub.com/api/media/14632576-c89b-496d-beb1-f40932a76a6a/video.mp4

## Entry 20
- ID: 8077
- Author: Brandon
- Created At: 2026-05-20T03:04:15Z

### Content

When shopping for the components for the Walkman PCB, I tried to use JCLPCBs feature where I would upload a BOM of my project and they would automatically pull up all the components that I would need all on the JCLPCB website, so that I could order them all without having to manually search for them.
Reality isn't that simple, however, because when I searched up the XIAO ESP32 S3 (my MCU), JCLPCB showed that I could only order it when I used their "PCBA" service, which means that I could HAVE to pay them to assemble it, not just deliver the components separately with the PCB, which would end up costing me more money, which isn't desirable.
Screenshot 2026-05-19 214245.png
After finding links online that I could use to purchase all the components, the only troublesome one to find was the MAX98357A Amplifier.  For the MAX98357A, I couldn't find a breakout board footprint for my PCB Editor, and the only footprint that I was able to find is the smaller version (the Quad Flat No-Lead package), which only has flat metal parts that need to be soldered onto the PCB directly, and it doesn't have pins to guide soldering.  This meant that soldering this component would be very difficult, as a small mistake could end up in the whole amplifier not working properly.
Screenshot 2026-05-19 215015.png
Screenshot 2026-05-19 223823.png
I'll ask my engineering teacher for help on this, and maybe some of my peers if they can provide some replacements for this amplifier.

### Recording Links

- https://lookout.hackclub.com/api/media/77460058-c71a-43a5-8f47-4bcd787b8f62/video.mp4

## Entry 21
- ID: 8572
- Author: Brandon
- Created At: 2026-05-23T02:49:57Z

### Content

With the soldering eminent, I decided to research more about if I could solder all the components using just a regular soldering kit, like a Pinecil or something.  Turns out that for most of the components, yes, because I had made sure that most of them use THT (Through-Hole) pins, and therefore allowed a lot of room for error. 
Screenshot 2026-05-22 203221.png
 However, I had some "Surface Mount" components, namely the PCM5102 and the microSD card slot.  And to add to that, there were the BSS138 components that had to be surface mounted also: luckily, I found a footprint for the BSS components that allowed for a larger error margin.
Here's the comparison of when I changed the footprint for the BSS (I changed the the larger footprint for it):
Screenshot 2026-05-22 202326.png
I didn't realize that I forgot to press F8 to update my PCB Editor for the resistor ladder, so when I updated it to bring in my large BSS footprints, I was surprised to get a whole slew of DRC errors about some "short circuiting"?  Turns out with my current track and wire configuration, I was connecting a lot of GPIO pins directly to power pins (e.g. 3V3 pins).  I also saw some blue "requirement" lines that confused me, as they were already connected:
Screenshot 2026-05-22 210057.png
After I deleted the extraneous connections, through, I was able to correct the tracks and wiring.
I also ended up deleting the Connector 01x02 component from the PCB, after using a past (guided) PCB project that had battery wires go through a punched hole in the PCB to have its wires itself become pins for soldering (it's an audio recorder):

Getting some help with Claude, I deleted the component, and wired a new component called "Jumper" directly to the GND and the power pin.
Screenshot 2026-05-22 212337.png
Looks much cleaner! (also saves me some money)

### Recording Links

- https://lookout.hackclub.com/api/media/549c812f-7b8f-4877-ad81-e96325f5bbf0/video.mp4

## Entry 22
- ID: 8780
- Author: Brandon
- Created At: 2026-05-24T03:22:38Z

### Content

I decided that Surface-Mounting Soldering was definitely not for me, and after having found the larger footprint for the BSS components, I wasn't about to go smaller than those footprints for any other component, and that included the PCM5102A component that I was using for audio conversion.  The raw component itself looks like it has less than 1mm of tolerance when soldering it, so instead of trying to suck it up and try to solder the microscopic pads for myself or resorting to having JCLPCB solder it for me (PCBA), I turned to another solution: Amazon!
I was planning to buy a board from [this link](https://www.amazon.com/PCM5102-PCM5102A-Digital-Converter-Raspberry/dp/B0DNW32Y46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), it seems like a good deal.  Another thing: the module includes an AudioJack as well!
Well, it perplexing at first to figure out which of my previous pins should go to relative to the module, because originally I had imported the PCM5102 and the AudioJack symbols separately onto the Schematic and manually wired them together as per their datasheets, but now all I had was this to work with as a "datasheet".
Screenshot 2026-05-23 221242.png
Given that I found this module on Amazon instead of a electronics vendor, I found no footprint files or anything, so I had to make my own custom symbol (in which I forgot to give each pin a number, which I'll have to fix in next session).
Screenshot 2026-05-23 222311.png
I made a footprint for it also, but considering that it's a module, I just slapped on a Connector 01x15 on my PCB Editor.  It's pretty longggggg.
Screenshot 2026-05-23 222346.png
Most of my time as allocated to reorganizing the tracks and wires on the PCB Editor, but seeing as to how messy the editor became after my shift to the module, which entailed the deletion of a whole lot of resistors and capacitors, as well as the deletion of the AudioJack and the PCM5102A themselves, I couldn't simply just rewire: I had to do some "track and wire demolition" to clean it all up.  Here's a before and after of the edits I made today: the track and wire clean ups will continue next session.


### Recording Links

- https://lookout.hackclub.com/api/media/dcd21fd8-4de7-4ac4-a70e-f2e3dfff6cf8/video.mp4

## Entry 23
- ID: 9026
- Author: Brandon
- Created At: 2026-05-25T03:55:23Z

### Content

With my Amazon delivery coming in for my LED project components, I also got some components in for the Walkman project, such as the PCM5102A x Audio Jack module

After fixing the custom symbol for the PCM5102A x the Audio Jack and rearranging the components to make the PCB smaller, I got to work for wiring the new PCB version that I had for the Walkman.
After grinding for a bit, I got a zero-error DRC check :)
Screenshot 2026-05-24 233313.png
Screenshot 2026-05-24 233411.png

### Recording Links

- https://lookout.hackclub.com/api/media/3eefe05a-84d3-42b4-9a87-87320b506ef0/video.mp4

## Entry 24
- ID: 9152
- Author: Brandon
- Created At: 2026-05-25T17:14:33Z

### Content

Here's a comparison between the two iterations of my Walkman PCB thus far:

Even though the dimensions aren't much smaller, at least I have no vias now :)
With the physical PCM5102 x Audio Jack with me, I measured out the dimensions of it (roughly 18 mm x 32 mm), so that I could make a little socket for it on my PCB in the OnShape rendering.

Exporting the newer version of the Walkman PCB, I CADed until my mouse broke (hyperbole), and drew all over my OnShape document into oblivion: after this session, I began printing the custom standoffs that I had created to verify their stability (as in making sure that they weren't too microscopic to work with).


### Recording Links

- https://lookout.hackclub.com/api/media/c1323cd9-1d13-40a9-ad3b-ee44cf9a60c6/video.mp4

## Entry 25
- ID: 9505
- Author: Brandon
- Created At: 2026-05-27T01:29:09Z

### Content

From yesterday's CADing session, I managed to print the custom standoff/case for the PCM5102A + AudioJack module (the printing time was NOT INCLUDED IN THIS SESSION'S TIME), and it fits pretty well!

Moving on, I started to CAD the Walkman case, but as I made progress in make it (starting from the bottom of the PCB board), I noticed that my fingers most likely won't be able to go through the case in order to press the buttons (SW_PUSH buttons, in order to pause, play, skip, etc).  Even if I were to make an indent big enough to fit my fingers, the case will be very awkward to install, not to mention very open and have the PCB left open to the elements (i.e. rain).

This was when I decided to finally search for a right-angle switch: I wasn't looking for one earlier because I assumed that they didn't exist.  I was browsing through KiCad's built-in switch footprints, and none of them seemed to work (most of the footprints didn't have valid 3D models to be shown on the 3D Viewer T-T) However, to my luck, there are quite a few "upright" switches out there on the internet, and I even found a Right-Angle Tactile Button" on the LCSC database!  Using easyeda2kicad via Powershell, I imported the "TC-S3601-3.5-260G-F0.6" into my Walkman project, assigned it to the 5 SW_Push switches that I had, and then rendered them on the 3D Editor: it looks pretty good! (Unfortunately the switches are SMD/surface-mounted, hopefully I can do that)
Coming up next, I'll have to rewire the PCB (yet) again, and render the new3D  version of the PCB in Onshape to make a case for it.

### Recording Links

- https://lookout.hackclub.com/api/media/d53d0c67-e778-4433-8d94-ddbf1983cd47/video.mp4

## Entry 26
- ID: 9509
- Author: Brandon
- Created At: 2026-05-27T01:54:52Z

### Content


This time, rewiring everything for the new switches wasn't too hard, except this one GPIO1 pin connection, which required me to track a F. Copper (because the switches are SMD/Surface-Mount) all around the bottom of the PCB in order to not use a via (after all, I don't want to only use 1, that'll feel terrible, might as well use no vias).

### Recording Links

- https://lookout.hackclub.com/api/media/98271124-ea61-4c9b-931a-f127619c8ffc/video.mp4

## Entry 27
- ID: 9699
- Author: Brandon
- Created At: 2026-05-27T17:10:28Z

### Content

The other night, I was vacillating about wanting to buy the right-angle switches from LCSC immediately due to me being unsure if I had any other components out of all my PCB projects that I need to buy from LCSC.  Wanting to review my purchases, I updated my PCB BOM Google Doc to track all of my purchases and expenses.
Moving on; when I tried exporting my Walkman PCB, the right-angle switches came out wrong, **despite looking correct in the 3D Viewer**!  My first suspicion was that something was awry in the DRC (I forgot to check the DRC after switching to right-angle switches, actually :| ), and lo and behold, there was something wrong (albeit it wasn't the cause of the broken 3D model):
Screenshot 2026-05-27 113622.png
After repeated research, I initially thought that the DRC errors were stemming form how the 1 and 2 pin pads were too close to the two through-holes, so I tried scaling them smaller and moving the pads farther away from the holes, but all those methods didn't alleviate the problem.  After further research, I discovered that the through holes themselves were the problem, because they were the **wrong type of through-holes**!  They were **copper** through-holes instead of being **mechanical** through-holes, and the latter type was the correct one due to the holes only being necessary to provide a slot into which the switch can slide into (it has two pegs on the bottom that line up with said holes).
Screenshot 2026-05-27 120203.png
After changing the parent footprint of the right-angle switch to have the correct type of through-holes, I updated the rest of the switches to be correct, and thus the DRC errors disappeared!  (idc about stupid silkscreen Warnings, shut up KiCad)
Screenshot 2026-05-27 120518.png
As I had mentioned before, though, these DRC errors weren't the cause of the misalignment seen in the 3D export of my PCB (.step):
Screenshot 2026-05-27 120701.png
The errors persisted even in the .stl version of the 3D export:
Screenshot 2026-05-27 121824.png
Soon, I later learned that the 3D rendering that I was seeing in KiCad was actually a DIFFERENT file than what the .step and the .stl files were using to render the right-angle switches!  The rendering on KiCad **3D Viewer** was using the .wrl (a Blender filetype) version of the switch 3D file, while the export was using a .step filetype for all the components, and the .step file was secretly misaligned according to the PCB coordinates: I just didn't notice it because all I was seeing was the .wrl version of the switch, which was all correct.
When swapping the 3D Viewer in KiCad to use the .step file instead, the misalignment became apparent:
Screenshot 2026-05-27 122201.png
After fixing this file mismatch, I finally got a correct export of the PCB in the form of a .step file (.step files are so cool, better than .stl for sure)
Screenshot 2026-05-27 123423.png

### Recording Links

- https://lookout.hackclub.com/api/media/6f7e2ba0-582d-431a-b0f8-310f3dec8b4d/video.mp4

## Entry 28
- ID: 9972
- Author: Brandon
- Created At: 2026-05-28T18:17:04Z

### Content

As I started making the case for the Walkman, yet again, I had questioned my PCB's design: this time, it wasn't about the five SW_PUSH buttons that I replaced, but was struck by a doubt: even though I used a battery cage of two AA batteries to power a PCB before (it was an audio recorder, pretty simple), would it power this PCB the same?  Yesterday, I did some research about a new PCB project that I was planning, and the power consumption for it was relatively more compared to my other PCB projects (including this one), and one main component that all the AI model assistants that I used for research all implored me to use some ["TP4056"](https://www.amazon.com/MakerFocus-Charging-Discharging-Interface-Protection/dp/B0CWNXKR4X), which is supposed to regulate the power between a battery and the XIAO and the rest of the PCB.  I didn't use something like this in my past PCB project!
Advice told me to use a LiPo battery, short for "Lithium Polymer", instead of a simple set of Alkaline batteries.  Makes sense in hindsight, however, because I want to be able to recharge my Walkman.
Alas, after much research and crashing out in front of Claude, Gemini, and other AI models for advice, I found myself surfing the web to look for answer on how to properly use a LiPo) battery, here's all the videos I looked at: some were confusing, others were quite helpful.
https://youtu.be/V_mZsiZcy7s
https://youtu.be/gmx536ov7i8 (wrong context because this is for much higher power demand, off-road RC cars)
https://youtu.be/o0TiboxnwWA
https://youtu.be/doyDc18SwfE
I also used this screenshot a lot when trying to explain that I was using a XIAO ESP32S3 that has a USB-**C** port, but a USB-**A** port.
Screenshot 2026-05-28 115512.png
After two long hours or doubt and searching, I discovered that there were two hidden pins on the backside of the XIAO ESP32S3, which were BAT+ BAT- for the LiPo battery to use.  This led me to make a design decision to raise the XIAO by a few millimeters to make room in which the wires for the battery wires can snake though to attach to the backside of the XIAO.
Screenshot 2026-05-28 120619.png
The lone connector represents the BAT+ pin, which will connect to the BAT+ pin/pad on the XIAO.
Screenshot 2026-05-28 122826.png

### Recording Links

- https://lookout.hackclub.com/api/media/ba6058f5-c3dd-450f-8589-5e6819ad06fb/video.mp4

## Entry 29
- ID: 10186
- Author: Brandon
- Created At: 2026-05-29T17:32:34Z

### Content

Today's progress can be summed up in six words: "one step back, one step forward".
I was in New York visiting family, when I realized that I had forgotten to push my KiCad changes to my GitHub repo from home, and the last time I did was was like a couple of weeks ago (dang it!) so I had to call my brother who was still home, where my desktop was in order for him to push the changes for me (he knows my computer password now...).
My brother also decided to name the commit name "larp" cause that's his favorite word nowadays, what a silly guy.
I also had to update some of the footprints and symbols and 3D models because even though they were saved on my desktop computer, they weren't saved on my laptop computer that I had to use, and they weren't in the GitHub as well.  Luckily, I have my BOM on Google Docs, so I could use the easyeda2kicad cmd tool to bring over the necessary symbols, footprints, and 3D models.  
Using easyeda2kicad on my laptop was a bit trickier, because I didn't notice that my file paths were going under the pesky OneDrive/ folder.  This took me about 20 minutes to realize :(
Screenshot 2026-05-29 125104.png
Screenshot 2026-05-29 125118.png
Also, the 3D models on the PCB editor for the right-angle switches weren't appearing, and supposedly there were two references to the 3D models and footprints for the component: one set in the "Global Libraries" tab, and the other in the " Project Specific Libraries" tab, which somehow caused a problem.  When I deleted the latter version of the easyeda2kicad library, everything looked as normal, and better yet, I didn't have to adjust the offsets for the 3D offsets for the 3D Viewer!
Screenshot 2026-05-29 130241.png
Screenshot 2026-05-29 130247.png

### Recording Links

- https://lookout.hackclub.com/api/media/6cab809b-ef46-4a02-9cd1-0794b84988e9/video.mp4

## Entry 30
- ID: 11538
- Author: Brandon
- Created At: 2026-06-04T04:29:34Z

### Content

With me deciding that the XIAO ESP32S3 needing to be off the surface of the PCB, I looked at [the connectors that I was going to buy](https://www.amazon.com/Glarks-Connector-Assortment-Stackable-Breakaway/dp/B07CWSXY7P) to ensure that the LCD and the XIAO would have connectors at the same height in the 3D rendering (after all, I'm only getting one set/kit of connectors/pin headers).  I deduced that the total height between the components and the PCB should be 10mm (8mm + 2mm) for both the XIAO and the LCD screen.
Screenshot 2026-06-03 154534.png
Fixing the distance (i.e. Z-offset) for the XIAO, I realized that the connectors in the LCD 3D model rendering didn't match the connectors that I was going to buy from Amazon, so I had to edit the LCD's offset as well, even though the connectors would look like they're clipping through the PCB in the 3D model (while in reality, they wont).
Screenshot 2026-06-03 162126.png
Now they're level with each other!
Screenshot 2026-06-03 155829.png
I also noticed that the pin header that I was using for my LiPo battery from the back of the PCB seems to be smaller than the rest of the pins, and it was because it was using a 1mm x 1mm pin header instead of the standard 2.54mm x 2.54mm, and after changing that in the Footprint Editor (I couldn't change it in the PCB Editor > Properties), I finally exported the .step 3D file for the PCB into OnShape.

After this, I went on my phone for a bit to order some of the Walkman components from DigiKey to get that task knocked out.  (They don't have International Direct Shipping or whatever it is, the cheapest delivery they have is USPS Ground T-T)
This session was done entirely on my (crappy) laptop, which is why I wasn't as productive as I could've been during this session)

### Recording Links

- https://lookout.hackclub.com/api/media/7f407e9f-4e37-4dce-be4b-ff870c2f9db4/video.mp4

## Entry 31
- ID: 14262
- Author: Brandon
- Created At: 2026-06-15T15:55:51Z

### Content

When I got my order from DigiKey, I realized that my Omron SW SPST switches were wrong for my power on/off case!  After looking at a friend's KiCad project, I copied his schematic and usage for a power switch (i.e. a SW DPST instead of a SW SPST).
Screenshot 2026-06-13 111224.png
After getting back from a trip from Colorado, I managed to talk to one of my more PCB-savvy friends online and discussed past projects that he had done with XIAO's. Through these conversions, I learned how he implemented batteries and power management within his PCB projects, in some ways more sketchier than others.  For example, he told me that when soldering jumper wire holes (punched holes) to the battery pads on his XIAO, he only used the solder, making a "melted solder trail" from the jumper wire holes to the pads, which, as he admitted, was indeed sketchy.  We were discussing how to connect the BAT+ and BAT- (i.e. the battery pads) on my XIAO to my SW_SPDT power switch and the LiPo battery that my friend suggested.  What I had initially was using a pin connector to plug into a JST connector onto the PCB, and then to have another wire connect that pin connector to the battery pads through direct SMD soldering: better than making a melted solder trail, but still sketchy.  That's when my friend proposed that I directly make the battery pads on the back of the XIAO come into contact with the PCB.  That's when I remembered that it is indeed possible to have a footprint on a PCB just be a simple surface/SMD pad of exposed copper to solder onto, so I did just that.  Using the footprint editor on the official KiCad document from Seeed Studio (the group that made the XIAO series), I identified the dimensions of the pads, and the distances they were from the tip of the USB-C outlet.  
Screenshot 2026-06-13 142634.png
Screenshot 2026-06-13 143205.png

Screenshot 2026-06-13 150057.png
Screenshot 2026-06-13 151325.png
After checking my work using the 3D Viewer, it turns out that my dimensioning was pretty accurate!
Screenshot 2026-06-13 153420.png
Also, I spent a lot of time after the XIAO power distribution change to rewire everything on my PCB to make it more compact, where I had to use 9 vias, because I decided that a smaller size was worth the addition of vias in my PCB design.

### Recording Links

- https://lookout.hackclub.com/api/media/786ff3d8-b553-4803-a038-e6dd8a68ad80/video.mp4

## Entry 32
- ID: 14669
- Author: Brandon
- Created At: 2026-06-17T02:00:24Z

### Content

Upon receiving the LCD1602 from Amazon, I took a look at it:


I noticed that there was an auxiliary board attached to it: what would it be?  I started to look back on the [Amazon link]() which I got the LCD from, and sure enough, it said that it came with a PCF8574, which worried me because I wasn't sure if I was using the PCF.  After a look at my BOM, however, I actually do indeed use the PCF8574, and since it's already attached to the LCD out of the package, I didn't have to worry about the PCF taking any more space on the PCB!  Therefore, I went ahead and deleted it from the schematic and the PCB editor.
This also meant that I had to create a custom symbol and footprint for the PCF x LCD combo, and after fumbling through the measurements for the components' pins, I got it on the PCB editor.
Screenshot 2026-06-15 125114.png

Note that the right-angle pin connectors will make it impossible for me to install the LCD onto my PCB board as intended, as the LCD would now be sticking up and out of the board instead of being flat against the PCB board's surface.  Thus, I'm in the process of (carefully) bending the right-angle connectors straight.  Due to the potentiometer for tuning the LCD's brightness is also on the backside of the LCD, I'll have to use a provided JST connector (that came with the component) to test the brightness before fully installing it (i.e. soldering it) onto the PCB, which will be my Walkman.

This isn't a final version of the PCB board, however, as I still have more wiring to do, as well as add the PCM5102 x AudioJack combo onto the PCB editor as its own footprint, because I changed my mind about keeping it as a row of Pin Connectors, and I want to give it its own footprint as I had given the PCF x LCD combo.

### Recording Links

- https://lookout.hackclub.com/api/media/8bb49337-191b-4874-89d2-8837a6cf05f2/video.mp4

## Entry 33
- ID: 14899
- Author: Brandon
- Created At: 2026-06-18T01:25:20Z

### Content

Before I went ahead and made the footprint for the PCM + AudioJack component, this is where I had left off since last session.  With the plentitude of lines streaming across the editor, it was foreshadowing as to how long this session would take in order to wire the components all back together.
Screenshot 2026-06-15 140439.png
This is when I started customizing the footprint for the component:
Screenshot 2026-06-15 141042.png
Screenshot 2026-06-15 141359.png
Finally, it took be about a couple hours and a lot of deep breathing (it wasn't that hard...) to finally be rewarded with a 0-error DRC report :D
Screenshot 2026-06-15 165358.png
My usage of vias was still a lot by my standards, albeit minimal, around 8-15.

### Recording Links

- https://lookout.hackclub.com/api/media/5cc80606-33cc-4b6f-b236-0f9903fcf221/video.mp4

## Entry 34
- ID: 15139
- Author: Brandon
- Created At: 2026-06-19T03:16:50Z

### Content

This session, I first discovered that the LCD + PCF component footprint I made was wrong!  Using my DigiKey ruler yet again, I measured out the lengths of all the pin dimensions from the edge of the LCD board, and tediously inputted all their measurements onto the footprint.  So, this also meant that I had to change the routing on the PCB Editor.  
This is a picture of my verifying the new dimensions and placements of the pins for the LCD + PCF component.

Then, I noticed that there was a "5V" pin on the LCD + PCF component that was empty (i.e. not routed to anything) and mislabeled (it was supposed to be the VCC, which would be the XIAO's VBUS pin).  I decided that it was time to update my schematic and fix all the wrong and missing wirings, if any.  I later learned that the 5V/VCC pin on the LCD + PCF component should've been connected to the VBUS pin from the XIAO, and after further inspection of the "bidirectional I2C level shifter", aka the BSS138, I realized that I wired it wrong in the schematic.
I know this because of a reference image I found online, showing the correct way to wire a BSS between to levels (in my case, the lower-level "LV" would be the 3.3V from the XIAO's side, while the higher-level "HV" would be the 5V from the VBUS and LCD + PCF's side).
Screenshot 2026-06-17 141005.png
I used labels differently to help me understand what was going on in the schematic.
Screenshot 2026-06-17 140620.png
On the right side of this image you'll see the custom symbol I made for the LCD + PCF component.
Screenshot 2026-06-17 140930.png
With the new schematic, I returned to the PCB Editor, pressed F8 to update it, and got back to wiring.
Screenshot 2026-06-17 141431.png
Screenshot 2026-06-17 142124.png
Once again, the amazing Brandon wires everything together with no DRC errors on the first try!
Screenshot 2026-06-17 143231.png

### Recording Links

- https://lookout.hackclub.com/api/media/62045419-c02e-4d07-a1a9-3880c5e7c5d0/video.mp4

## Entry 35
- ID: 15405
- Author: Brandon
- Created At: 2026-06-20T01:01:07Z

### Content

If I wanted to make a 3D printed housing for my PCB (it better not be out and about exposed to the elements...), I had to either:
One: Find the 3D models of the custom components that I bought from Amazon online on the interwebs

**OR**
Two: Dimension the components myself a bajillion times to make sure that I have everything correct (I really didn't want to do this, for this leaves a lot of room for error, and I would rather not 3D print many different attempts of making a housing if the failed versions are just a couple millimeters off)
This [Amazon link](https://www.amazon.com/Hosyond-Display-Module-Arduino-Raspberry/dp/B0BWTFN9WF?ref_=ast_bl_cpl_dp) that I used to buy the LCD + PCF component didn't have a 3D model component linked to it, so I went looking elsewhere for an accurate 3D modelling for it.  Good news was, I found one on [Autodesk](https://www.autodesk.com/community/gallery/project/155964/lcd-1602-i2c), but the bad news was that the file was a f3d file format, a format exclusive to Fusion.  This meant that I had to find some way to convert it into a STEP or STL file in order to be about to use it in my PCB Editor for my LCD.
That said, I'll have to continue looking for the AudioJack + PCM component's 3D model some other time (or...I could dimension it myself; this component is not as bad because it's more "flatter" than the LCD)
After signing up for an Autodesk free trial account, I went though many tutorials online to help me get to the part where I could finally import my f3d file into a STL file, and when I imported it into OnShape, I turned it into a STEP file which I used to represent the LCD in the KiCad PCB 3D Viewer.
Screenshot 2026-06-18 225502.png
Many more iterations were done in terms of aligning the 3D model of the LCD to the mounting holes on the board, and then measuring the difference between the pins on the LCD vs on the board, and then going back tot he footprint editor for the LCD to change the positions of said pin holes.
Screenshot 2026-06-18 230116.png
I had to move the dimension of the LCD and pin holes for about three cycles until I got the positioning right (I think...I'll have to see when I actually 3D print this new version of the PCB to verify the correct dimensioning of the PCB's holes to the LCD's pins.
In KiCad, though, this looks correct.
Screenshot 2026-06-18 231322.png

### Recording Links

- https://lookout.hackclub.com/api/media/7ab3bcfd-ab04-411a-8d7f-de37684c221d/video.mp4

## Entry 36
- ID: 15952
- Author: Brandon
- Created At: 2026-06-21T04:03:14Z

### Content

On June 19, I finally got the XIAOs from China, which meant that I could finally verify dimensions of the BATT pads on the XIAOs and compare them to their estimated dimensions that I had on my XIAO KiCad footprint.

Exporting the Walkman PCB as a STEP file, I made another test print for the PCB board that, when printed, will show me if the BATT pads dimensions and positions match with the real XIAO (that I'm holding in the picture).
XIAO bat pad comparison.jpg
As for the LCD, I managed to verify its pins' positions on a previous PCB test print, as shown:

One thing I realized about the LCD's orientation on the PCB, through, is that the display was shown to be upside-down according to the 3D model that I retrieved from a previous, recent session, so I had to rotate the LCD's footprint in the PCB Editor by 180 degrees and rewire its pins' tracks.
Moving on, I decided to measure the AudioJack + PCM component's dimensions using my DigiKey-branded ruler, and CADed its rough design and shape on OnShape, which I later exported as a STEP file and added to the PCB's 3D model on KiCad.

After adjusting its positions on the 3D Viewer to align with the X and Y of the footprint, I saw that the AudioJack (3.5mm, by the way) was colliding with the right-angle buttons.
Screenshot 2026-06-19 201621.png
Raising the component by 2.54mm (I'm going to use a pin connector for it on the real PCB to give it that extra elevation), the component wasn't colliding with the switches/buttons anymore.
Screenshot 2026-06-19 201859.png
Screenshot 2026-06-19 201939.png
Finally, I exported the PCB to import it onto OnShape to help me make the 3D printed housing for it.  Unfortunately, there were issues with exporting it as a STEP file, for the LCD would vanish in the file format, so I had to resort to using STL to export the PCB.  I hope that I don't have to restart making the housing because of yet another PCB addition this time...

### Recording Links

- https://lookout.hackclub.com/api/media/c2e94805-d0f2-42f8-bb2d-849d7580b000/video.mp4

## Entry 37
- ID: 16097
- Author: Brandon
- Created At: 2026-06-23T17:12:05Z

### Content

All that's left are some finishing touches to verify dimensions, and then I was going to plan to order the PCB.
Using OnShape to print some custom standoffs, I made sure that the pin locations for the LCD1602 and the standoffs would align to it.

Additionally, I also 3D printed a thin version of the PCB that had holes as to where the BATT pads on the XIAO were to ensure that the pads BATT pads on the PCB corresponded (touched each other) between the board and the XIAO itself.

Finally, my Walkman PCB order is now sent to JLCPCB, waiting to be manufactured and shipped.


### Recording Links

- https://lookout.hackclub.com/api/media/ef89657a-93c7-48b7-af75-a8e273279bcc/video.mp4

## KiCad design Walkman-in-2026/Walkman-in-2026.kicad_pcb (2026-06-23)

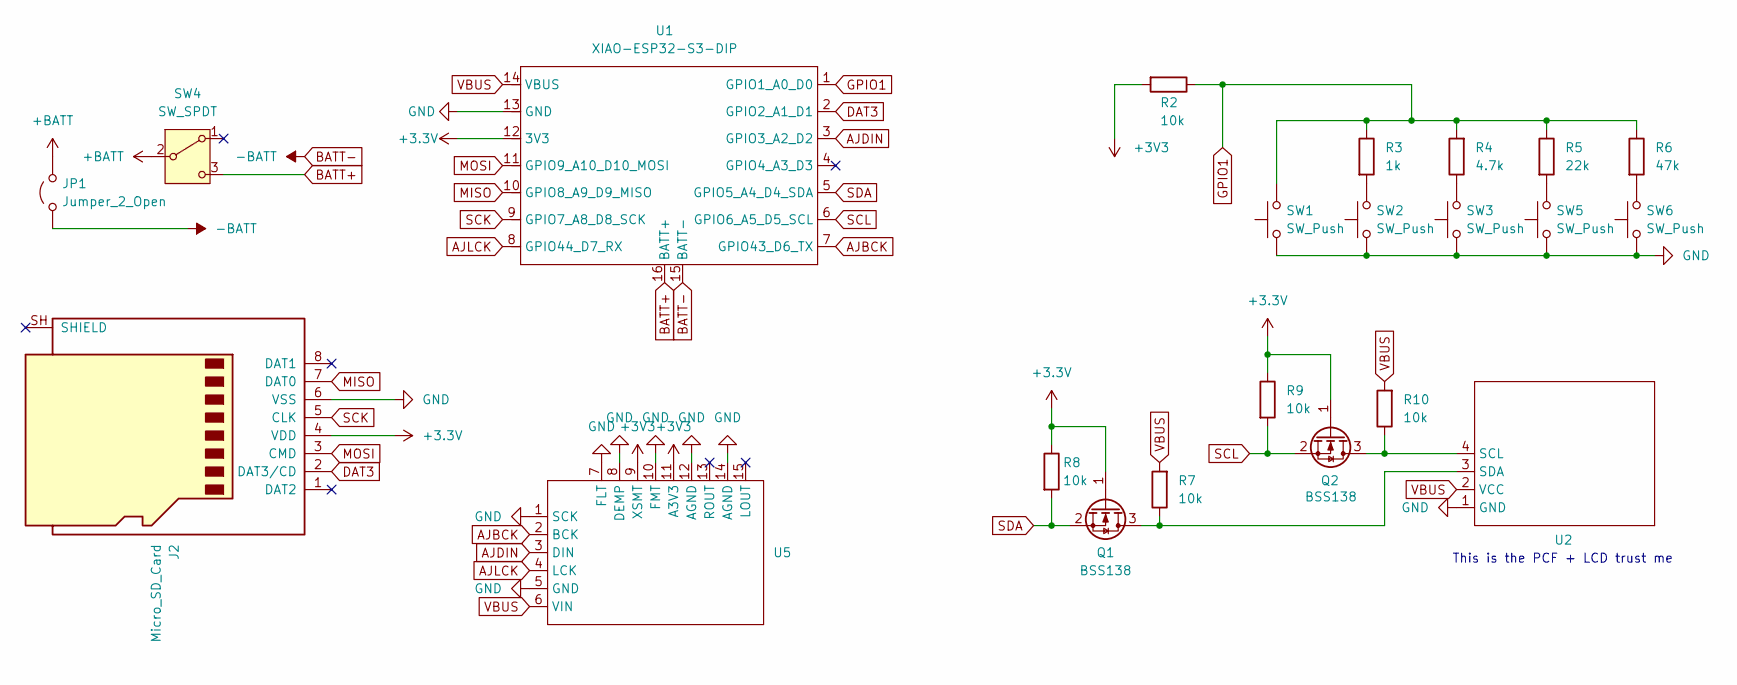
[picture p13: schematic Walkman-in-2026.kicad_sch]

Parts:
J2: Micro_SD_Card; microSD_HC_Molex_47219-2001
JP1: Jumper_2_Open; TestPoint_2Pads_Pitch2.54mm_Drill0.8mm
Q1, Q2: BSS138; SOT-23
R2, R7, R8, R9, R10: 10k; R_Axial_DIN0207_L6.3mm_D2.5mm_P7.62mm_Horizontal
R3: 1k; R_Axial_DIN0207_L6.3mm_D2.5mm_P7.62mm_Horizontal
R4: 4.7k; R_Axial_DIN0207_L6.3mm_D2.5mm_P7.62mm_Horizontal
R5: 22k; R_Axial_DIN0207_L6.3mm_D2.5mm_P7.62mm_Horizontal
R6: 47k; R_Axial_DIN0207_L6.3mm_D2.5mm_P7.62mm_Horizontal
SW1, SW2, SW3, SW5, SW6: SW_Push; SW-SMD_TC-S3601-3.5-260G-F0.6
SW4: SW_SPDT; SW_Slide_SPDT_Angled_CK_OS102011MA1Q
U1: XIAO-ESP32-S3-DIP
U2: PCF8574 x LCD1602 combo
U5: PCM x AudioJack Combo

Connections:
+3.3V: J2.4 (VDD), Q1.1 (G), Q2.1 (G), R8.1, R9.1, U1.12 (3V3)
+3V3: R2.2, U5.9 (XSMT), U5.11 (A3V3)
+BATT: JP1.2 (B), SW4.2 (B)
AJBCK: U1.7 (GPIO43_D6_TX), U5.2 (BCK)
AJDIN: U1.3 (GPIO3_A2_D2), U5.3 (DIN)
AJLCK: U1.8 (GPIO44_D7_RX), U5.4 (LCK)
BATT+: SW4.3 (C), U1.16 (BATT+)
BATT-: JP1.1 (A), U1.15 (BATT-)
DAT3: J2.2 (DAT3/CD), U1.2 (GPIO2_A1_D1)
GND: J2.6 (VSS), SW1.1, SW2.1, SW3.1, SW5.1, SW6.1, U1.13 (GND), U2.1 (GND), U5.1 (SCK), U5.5 (GND), U5.7 (FLT), U5.8 (DEMP), U5.10 (FMT), U5.12 (AGND), U5.14 (AGND)
GPIO1: R2.1, R3.1, R4.2, R5.1, R6.1, SW1.2, U1.1 (GPIO1_A0_D0)
MISO: J2.7 (DAT0), U1.10 (GPIO8_A9_D9_MISO)
MOSI: J2.3 (CMD), U1.11 (GPIO9_A10_D10_MOSI)
unnamed: Q1.3 (D), R7.1, U2.3 (SDA)
unnamed: Q2.3 (D), R10.1, U2.4 (SCL)
unnamed: R3.2, SW2.2
unnamed: R4.1, SW3.2
unnamed: R5.2, SW5.2
unnamed: R6.2, SW6.2
SCK: J2.5 (CLK), U1.9 (GPIO7_A8_D8_SCK)
SCL: Q2.2 (S), R9.2, U1.6 (GPIO6_A5_D5_SCL)
SDA: Q1.2 (S), R8.2, U1.5 (GPIO5_A4_D4_SDA)
VBUS: R7.2, R10.2, U1.14 (VBUS), U2.2 (VCC), U5.6 (VIN)

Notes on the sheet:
This is the PCF + LCD trust me

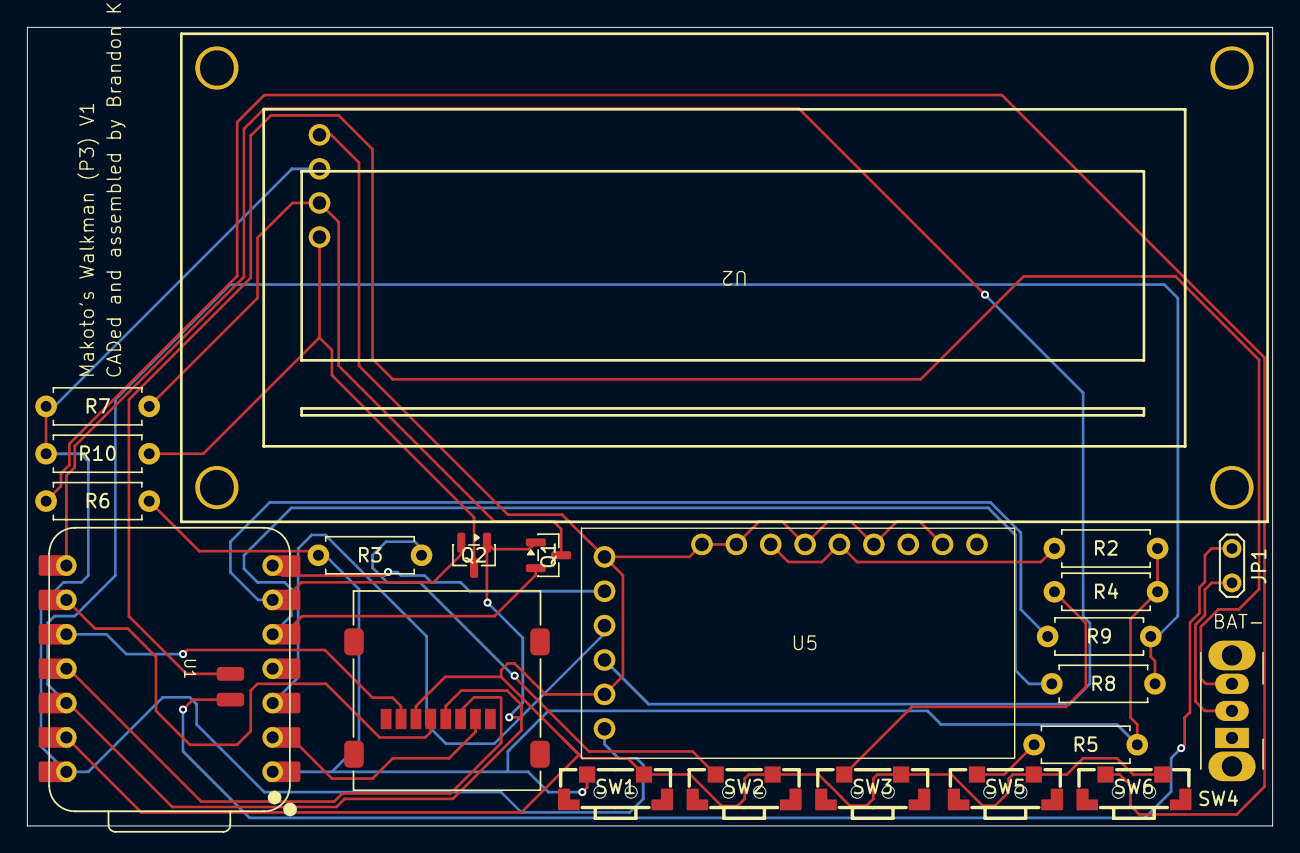
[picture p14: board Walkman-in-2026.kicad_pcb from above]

Board: 2 copper layers, 92.0 x 59.0 mm, 22 parts (0 on the bottom side), 23 nets.

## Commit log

2026-04-25 April 24 Session (Rerouting, Audio, Micro SD Card, and Setting Up Capacitors)
    [Walkman-in-2026.kicad_sch]
2026-04-27 jazz fest working
    [Walkman-in-2026.kicad_sch]
2026-04-28 moving on to the pcb editor
    [Walkman-in-2026.kicad_pcb, Walkman-in-2026.kicad_sch]
2026-05-04 May 3rd (end of worlds)
    [Walkman-in-2026.kicad_pcb]
2026-05-07 may 6 session
    [B3F_3150.step, Same_Sky_SJ1-3513N.step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]
2026-05-11 stuff happened ig
    [Walkman-in-2026.kicad_pcb]
2026-05-12 adding a fking stupid battery
    [Walkman-in-2026.kicad_pcb, Walkman-in-2026.kicad_sch]
2026-06-15 Adding custom footprints for lcd x pcf and pcm x audiojack
    [Walkman-in-2026.kicad_pcb, Walkman-in-2026.kicad_sch]
2026-06-23 v1 final
    [LCD 1602 I2C (pin removed).step, PCM + AudioJack.step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]
2026-06-24 Document version history and component updates in README
    Added detailed version history from V0.1 to V1.0, including changes to PCB design, components, and assembly notes.
2026-06-24 Update README with version history and project details
    Expanded version history and detailed changes for each iteration of the project, including component modifications and PCB adjustments.
2026-08-23 Update README with additional soldering supplies and notes
    Added section on additional supplies for soldering, including flux, heatbed, and solder paste. Updated assembly notes and included links to products.
